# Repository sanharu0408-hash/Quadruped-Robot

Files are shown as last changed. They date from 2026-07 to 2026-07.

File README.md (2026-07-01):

# 🐾 Quadruped Robot Project

https://www.youtube.com/watch?v=LkktNqY10M0

This project features a 4-legged walking robot controlled via an Arduino R4 and a Python-based PC controller.

## 📁 Project Structure

- `/Python_controller`: Python source code for PC-side control (Pygame & Serial).
- `/arduino_robot`: Arduino sketch for servo motor management (PCA9685).
- `/STL`: 3D printable parts for the robot chassis.

## 🖨️ 3D Printing Guide

Please print the following components from the `/STL` folder. 
The recommended material is PLA or PETG with at least 20% infill for durability.

| File Name | Quantity 
| :--- | :---:
| `frame_bottom.stl` | 1 |
| `frame_top.stl` | 1 | 
| `hip_1.stl` | 2 |
| `hip_2.stl` | 2 | 
| `left_knee.stl` | 2 | 
| `right_knee.stl` | 2 | 

## 🚀 Getting Started

### 1. Arduino Setup

1. Open `arduino_robot/arduino_robot.ino` in the Arduino IDE.
2. Install the `Adafruit PWM Servo Driver` library.
3. Upload the code to your Arduino R4.

### 2. Python Controller Setup

1. Install the required libraries:
   ```bash
   pip install pygame pyserial
   ```

2. Connect your controller (Xbox/PS4/PC Controller).

3. Run the application:
   ```bash
   python controller/main.py
   ```

## 🎮 Controls

| Button | Action |
| :--- | :--- |
| **B** | Toggle Walking Mode ON/OFF |
| **A** | kick |
| **X** | Jump |
| **Y** | Wave Hand |
| **L Stick** | Move Forward / Backward |
| **R Stick** | Turn Left / Right |

## 🛠️ Requirements

- **Hardware:** Arduino R4, PCA9685 PWM Driver, 8x MG90S Servos
- **Software:** Python 3.x, Arduino IDE

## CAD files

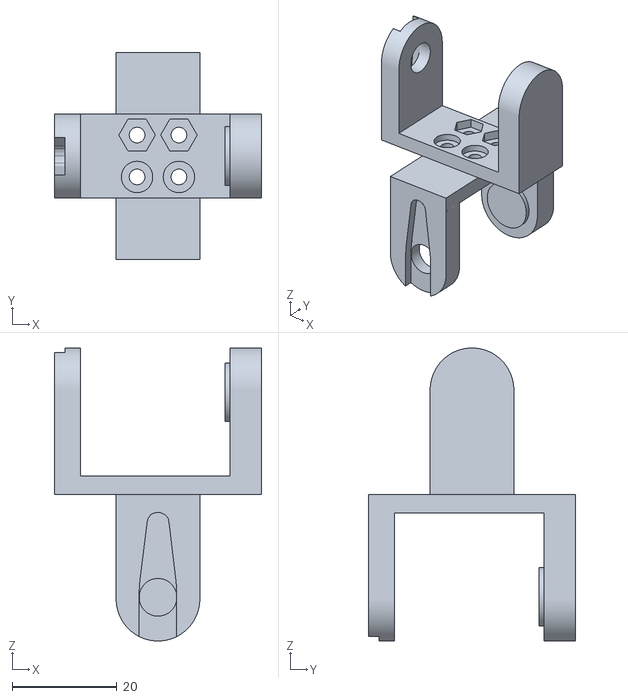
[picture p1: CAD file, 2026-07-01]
QuadrupedRobot_Project/STL/hip_2.STL
39.6 x 39.6 x 56.0

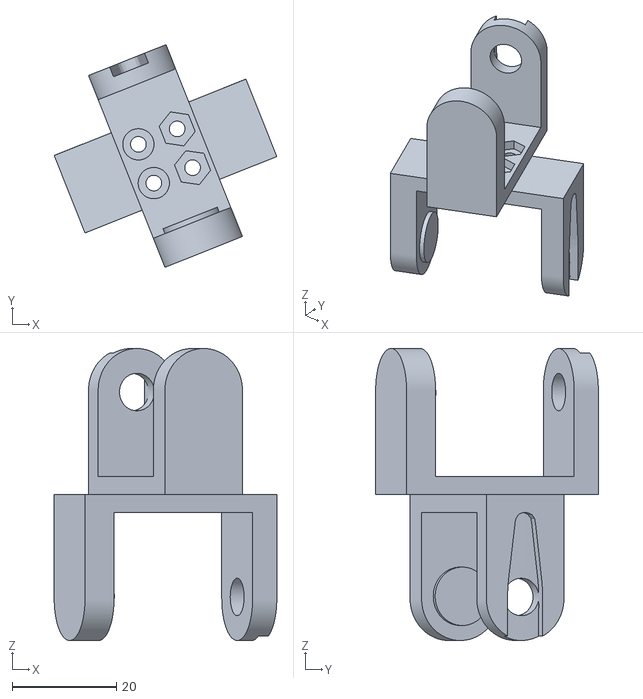
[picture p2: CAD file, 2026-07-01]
QuadrupedRobot_Project/STL/hip_1.STL
42.7 x 42.7 x 56.0

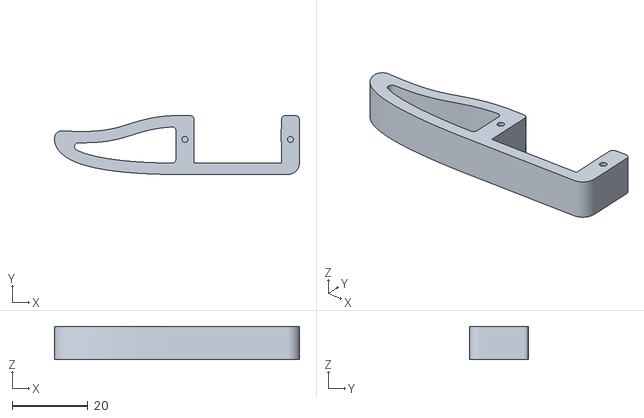
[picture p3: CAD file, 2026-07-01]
QuadrupedRobot_Project/STL/right_knee.stl
64.5 x 15.5 x 8.73

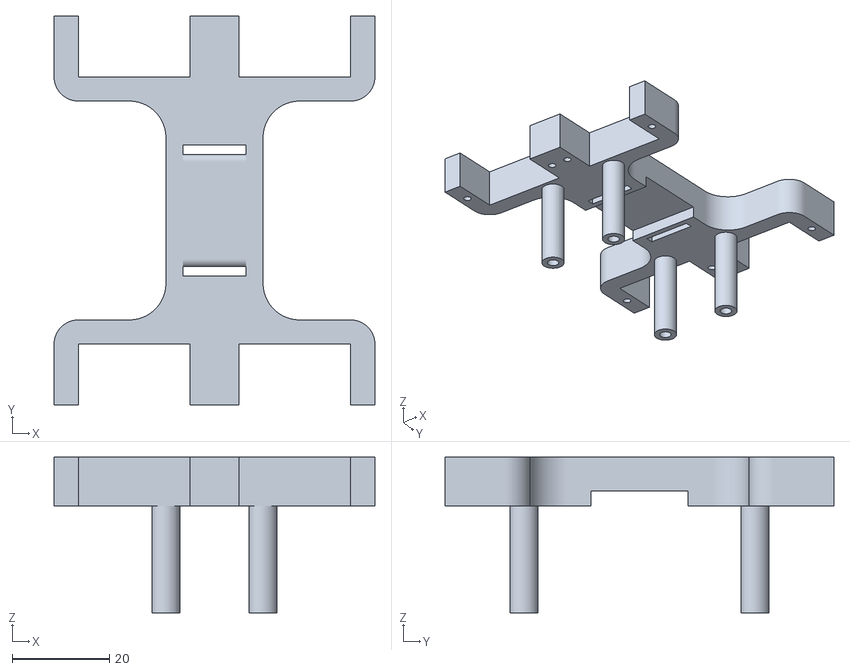
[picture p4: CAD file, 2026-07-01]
QuadrupedRobot_Project/STL/frame_bottom.STL
66.0 x 80.0 x 32.0

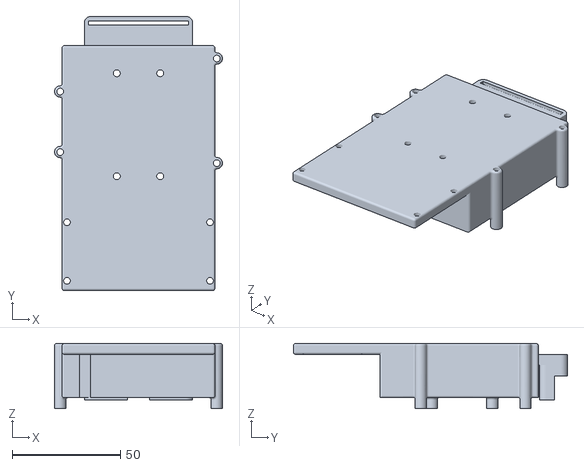
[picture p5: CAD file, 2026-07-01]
QuadrupedRobot_Project/STL/frame_top.STL
77.5 x 126.5 x 30.0

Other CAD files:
QuadrupedRobot_Project/STL/left_knee.stl

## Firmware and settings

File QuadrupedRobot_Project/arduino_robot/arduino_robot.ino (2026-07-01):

#include <Wire.h>
#include <Adafruit_PWMServoDriver.h>
#include <math.h>

 Adafruit_PWMServoDriver pwm = Adafruit_PWMServoDriver(0x40);

// -------------------- Servo Assignment (Centralized Management) --------------------
// Defines the index for each servo automatically: FL_KNEE=0, FL_HIP=1, etc.
enum ServoIndex {
  FL_KNEE, // index 0: Front Left Knee
  FL_HIP,  // index 1: Front Left Hip
  FR_KNEE, // index 2: Front Right Knee
  FR_HIP,  // index 3: Front Right Hip
  RL_KNEE, // index 4: Rear Left Knee
  RL_HIP,  // index 5: Rear Left Hip
  RR_KNEE, // index 6: Rear Right Knee
  RR_HIP   // index 7: Rear Right Hip
};

struct ServoConfig {
  String name;
  int ch;          // PCA9685 Channel (0, 2, 4...)
  int minPulse;
  int centerPulse;
  int maxPulse;
  int direction;   // 1 or -1
};

// -------------------- Servo Configurations --------------------
// Order must match the ServoIndex enum above.
ServoConfig servos[] = {
  // Name,      Ch,  Min,  Center, Max,  Dir
  {"FL_KNEE",   0,   145,  330,    520,   1}, // index 0
  {"FL_HIP",    2,   140,  325,    450,   1}, // index 1 (Max increased to 450 for kicking)
  {"FR_KNEE",   4,   140,  320,    520,  -1}, // index 2
  {"FR_HIP",    6,   275,  300,    485,  -1}, // index 3
  {"RL_KNEE",   8,   200,  310,    500,  -1}, // index 4
  {"RL_HIP",   10,   280,  305,    495,  -1}, // index 5
  {"RR_KNEE",  12,   100,  300,    400,   1}, // index 6
  {"RR_HIP",   14,   120,  300,    325,   1}  // index 7
};

const int SERVO_COUNT = 8;

int mode = 0;  // 0: Idle, 2: Walking
float waveAngle = 0;
float stick_Y = 0.0;
float stick_X = 0.0;

void setup() {
  Serial.begin(115200);
  
  // I2C anti-hang measures (specific to R4 noise safety)
  Wire.begin();
  Wire.setWireTimeout(25000, true); 

  pwm.begin();
  pwm.setOscillatorFrequency(25000000);
  pwm.setPWMFreq(50);
  resetToCenter();
}

// -------------------- Servo Control Functions --------------------

/**
 * Moves a servo to a specific position based on a ratio (-1.0 to 1.0)
 */
void moveServo(int index, float ratio) {
  ServoConfig s = servos[index];
  
  // Apply rotation direction internally
  float final_ratio = ratio * s.direction;

  float p_range = (final_ratio >= 0) ? (s.maxPulse - s.centerPulse) : (s.centerPulse - s.minPulse);
  float targetPulse = s.centerPulse + (final_ratio * p_range);
  int safePulse = constrain((int)targetPulse, s.minPulse, s.maxPulse);
  pwm.setPWM(s.ch, 0, safePulse);
}

// Reset all servos to neutral position
void resetToCenter() {
  for (int i = 0; i < SERVO_COUNT; i++) {
    pwm.setPWM(servos[i].ch, 0, servos[i].centerPulse);
  }
}

// Set Squat (Crouching) pose
void setSquatPose() {
  moveServo(FL_KNEE, -1.4); 
  moveServo(FR_KNEE, -1.4); 
  moveServo(RL_KNEE, -1.4); 
  moveServo(RR_KNEE, -1.4); 
  moveServo(FL_HIP,   0.0);  
  moveServo(FR_HIP,   0.0);  
  moveServo(RL_HIP,   0.0);  
  moveServo(RR_HIP,   0.0);
}

// Jump Action
void executeJump() {
  setSquatPose();
  delay(150);
  moveServo(FL_KNEE, 1.0); 
  moveServo(FR_KNEE, 1.0); 
  delay(35);
  moveServo(RL_KNEE, 1.0); 
  moveServo(RR_KNEE, 1.0); 
  delay(150);
  moveServo(FL_KNEE, 0.0); moveServo(FR_KNEE, 0.0);
  moveServo(RL_KNEE, 0.0); moveServo(RR_KNEE, 0.0);
  delay(80);
  setSquatPose();
  delay(200);
}

// Kick Action
void kick(){
  setSquatPose();
  delay(150);
  moveServo(FL_HIP, -1.0); // Use the expanded range for a powerful kick
  delay(150);
  moveServo(FL_KNEE, 0.0);
  delay(200);
  setSquatPose();
  delay(200);
}

// Wave Hand Action
void executeWaveHand() {
  // 1. Stability: Crouch 3 legs and bend Rear-Right knee deeply
  moveServo(FR_KNEE, -1.4); 
  moveServo(RL_KNEE, -1.4); 
  
  // Shift center of gravity to Rear-Right
  moveServo(RR_HIP,  -0.6); 
  moveServo(RR_KNEE, -2.5); 

  // Gravity compensation
  moveServo(FR_HIP,  -0.3); 
  moveServo(RL_HIP,   0.2);  
  delay(250);
  
  // 2. Extend Front-Left leg (the "hand") forward
  moveServo(FL_KNEE,  0.8);  
  moveServo(RR_KNEE, -0.4);  
  moveServo(FL_HIP,  -1.0); 
  delay(200);

  // 3. Wave the "hand" 3 times
  for (int i = 0; i < 3; i++) {
    moveServo(FL_HIP, -0.5); 
    delay(150);
    moveServo(FL_HIP, -1.3); 
    delay(150);
  }

  // 4. Return to Squat pose smoothly
  setSquatPose();
  delay(200);
}

void loop() {
  // Handle Serial Commands
  if (Serial.available()) {
    String input = Serial.readStringUntil('\n');
    input.trim();

    if (input.equalsIgnoreCase("w")) {
      mode = (mode == 2) ? 0 : 2;
      stick_Y = 0.0;
      stick_X = 0.0;
      if (mode == 0) setSquatPose();
    }
    else if (input.equalsIgnoreCase("j")) {
      executeJump();
    }
    else if (input.equalsIgnoreCase("h")) {
      executeWaveHand();
    }
    else if (input.equalsIgnoreCase("b")) {
      kick();
    }
    else if (input.startsWith("f") && input.indexOf(",r") != -1) {
      int rIndex = input.indexOf(",r");
      String fStr = input.substring(1, rIndex);
      String rStr = input.substring(rIndex + 2);
      stick_Y = fStr.toFloat();
      stick_X = rStr.toFloat();
    }
  }

  // ===== MODE 2: WALKING =====
  if (mode == 2) {
    if (abs(stick_Y) > 0.05 || abs(stick_X) > 0.05) {
      if (abs(stick_Y) > 0.05) {
        if (stick_Y > 0) {
          waveAngle += (0.04 + stick_Y * 0.04);
        } else {
          waveAngle -= (0.04 + abs(stick_Y) * 0.04);
        }
      } else {
        waveAngle += 0.04 + (2.5 * 0.04); 
      }
    }

    // Gait Phase Calculation
    float phaseFL = waveAngle;
    float phaseFR = waveAngle + PI;
    float phaseRL = waveAngle + PI;
    float phaseRR = waveAngle;

    float hip_phaseFL = phaseFL;
    float hip_phaseFR = phaseFR;
    float hip_phaseRL = phaseRL + PI;
    float hip_phaseRR = phaseRR + PI;

    float fl_knee, fr_knee, rl_knee, rr_knee;

    // Knee movement logic
    if (abs(stick_Y) > 0.05 || abs(stick_X) > 0.05) {
      fl_knee = (sin(phaseFL) - 3) / 2.0 * 0.7;
      fr_knee = (sin(phaseFR) - 3) / 2.0 * 0.7;
      rl_knee = (sin(phaseRL) - 3) / 2.0 * 0.7;
      rr_knee = (sin(phaseRR) - 3) / 2.0 * 0.7;
    } else {
      fl_knee = -1.4; fr_knee = -1.4; rl_knee = -1.4; rr_knee = -1.4;
    }

    // Steering calculation
    float base_Y = abs(stick_Y);
    float left_multiplier, right_multiplier;
    if (stick_Y >= 0) {
      left_multiplier  = base_Y + (stick_X * 1);
      right_multiplier = base_Y - (stick_X * 1);
    } else {
      left_multiplier  = base_Y - (stick_X * 1);
      right_multiplier = base_Y + (stick_X * 1);
    }

    left_multiplier  = constrain(left_multiplier, 0.0, 5.0);
    right_multiplier = constrain(right_multiplier, 0.0, 5.0);

    // Hip movement logic
    float fl_hip = cos(hip_phaseFL) * 0.6 * (left_multiplier / 5.0);
    float fr_hip = cos(hip_phaseFR) * 0.6 * (right_multiplier / 5.0);
    float rl_hip = cos(hip_phaseRL) * 0.6 * (left_multiplier / 5.0);
    float rr_hip = cos(hip_phaseRR) * 0.6 * (right_multiplier / 5.0);

    // Final Servo Output
    moveServo(FL_KNEE, fl_knee);
    moveServo(FL_HIP,  fl_hip);
    moveServo(FR_KNEE, fr_knee);
    moveServo(FR_HIP,  fr_hip);
    moveServo(RL_KNEE, rl_knee);
    moveServo(RL_HIP,  rl_hip);
    moveServo(RR_KNEE, rr_knee);
    moveServo(RR_HIP,  rr_hip);

    delay(20);
  }
}

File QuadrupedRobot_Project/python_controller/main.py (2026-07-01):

import sys
import serial
import pygame
import time

# --- Configuration ---
SERIAL_PORT = "COM3"
BAUD_RATE = 115200
DEADZONE = 0.2        # Joystick deadzone
LOOP_HZ = 20          # Loop frequency (Hz)

# Button Mapping (Standard Xbox Controller Layout)
BTN_A = 0
BTN_B = 1
BTN_X = 2
BTN_Y = 3

# --- Initialization ---
pygame.init()
pygame.joystick.init()

if pygame.joystick.get_count() == 0:
    print("[Error] No controller connected.")
    sys.exit()

controller = pygame.joystick.Joystick(0)
controller.init()

print(f"Connecting to Arduino on {SERIAL_PORT}...")
try:
    ser = serial.Serial(SERIAL_PORT, BAUD_RATE, timeout=0.1)
    time.sleep(1.5)  # Wait for connection to stabilize
    print("👉 Connected! You can now control the robot.")
except Exception as e:
    print(f"[Error] Failed to connect to serial port: {e}")
    sys.exit()

status_msg = "Idle"

print("\n--- Operation Guide ---")
print(f" B Button: Toggle Walking Mode (w)")
print(f" A Button: kick (b)")
print(f" X Button: Jump (j)")
print(f" Y Button: Wave Hand (h)")
print("------------------------\n")

print_counter = 0
clock = pygame.time.Clock()

try:
    while True:
        clock.tick(LOOP_HZ)
        pygame.event.pump()

        # --- Handle Button Inputs ---
        for event in pygame.event.get():
            if event.type == pygame.JOYBUTTONDOWN:
                if event.button == BTN_B:
                    ser.write(b"w\n")
                    status_msg = "Sent: Walking Mode Toggle"
                elif event.button == BTN_A:
                    ser.write(b"b\n")
                    status_msg = "Sent: kick (b)"
                elif event.button == BTN_X:
                    ser.write(b"j\n")
                    status_msg = "Sent: Jump (j) 💥"
                elif event.button == BTN_Y:
                    ser.write(b"h\n")
                    status_msg = "Sent: Wave (h) 👋"

        # --- Handle Stick Inputs ---
        # Axis 1: Vertical (Invert so up is positive)
        # Axis 2: Horizontal
        raw_Y = -controller.get_axis(1)
        raw_X = controller.get_axis(2)

        # Apply deadzone and scale
        stick_Y = round(raw_Y * 5.0, 2) if abs(raw_Y) > DEADZONE else 0.0
        stick_X = round(raw_X * 5.0, 2) if abs(raw_X) > DEADZONE else 0.0

        # Send stick data to Arduino
        msg = f"f{stick_Y:.2f},r{stick_X:.2f}\n"
        ser.write(msg.encode())

        # --- Update Terminal Display ---
        print_counter += 1
        if print_counter % 2 == 0:  # Reduce flickering
            output = f"\r[Status] {status_msg:<30} | [Stick] Forward:{stick_Y:+.2f} Turn:{stick_X:+.2f}"
            sys.stdout.write(output)
            sys.stdout.flush()

except KeyboardInterrupt:
    print("\n\nShutting down...")
finally:
    ser.close()
    pygame.quit()
    print("Cleaned up resources. Goodbye.")
